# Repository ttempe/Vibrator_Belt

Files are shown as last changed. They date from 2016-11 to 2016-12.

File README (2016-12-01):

Vibrator Belt. 
Copyright 2016, Thomas TEMPE

The purpose of this project is to build a (physical) vibrating belt as
a tool for sensory augmentation.  The belt is fitted with coin
vibrators along its length. The one that points north vibrates at all
time.  Use it continuously for 6 weeks, and you will grow a sense of
direction. Take it off, and you will experience amputation.

For more background (and an award-winning product that you can
actually buy), see http://www.feelspace.de/navibelt/

Directory contents:
Leather belt/		DXF files for manufacturing the flexible part 
			of the belt (fabric, foam, steel band...)
			Can be edited with LibreCAD.
Belt buckle/		Fusion360 model of the buckle (for aluminium 
     			machining or 3D printing)
Vibrator_Leather_Belt/	Kicad files for making the flexible electronic 
			circuit (along the length of the belt)
Vibrator_Leather_Belt_Control_Box/  Kicd files for making the PCB 
			circuit that fits in the buckle.
Photos/			Photos of prototypes.
Code/			Arduino code for the microcontroller.
Arduino/		Arduino hardware support for the microcontroller.

The control board uses an ATMega32u4 at 8MHz.
To get it running:
* Install the Arduino IDE from Arduino.cc. Run it once, then quit it.
* Copy Arduino/*/ into your Documents/Arduino directory
* solder an 8MHz external oscillator on the back of the control board
* Start the Arduino IDE. Select Tools->Board: -> Atmega32u4 on a breadboard (8MHz internal clock)
* Connect the ISP connector to an ISP programmer. Select the proper port in Tools->Port
* Click Tools->burn bootloader
* remove the external oscillator
* Tools->Board:->LilyPad Arduino USB
* File->Examples->01. Basics->Blink
* Click « Upload » on the icon bar. The « Signal » LED should blink with 0.5Hz frequency.
* open code/Compass_band5_leather/compass_band5_leather.ino in Arduino
* Click the « upload » icon on the icon bar. control code should be uploading.

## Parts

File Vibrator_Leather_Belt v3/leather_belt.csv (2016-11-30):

Reference | Value | Footprint | Datasheet
SR1 | 74HC164 | SMD_Packages:SOIC-14_N
C_IN1 | CONN_01X04 | ttempe_lib:Vibrator_Chain_Cnx_5
C_OUT1 | CONN_01X04 | ttempe_lib:Vibrator_Chain_Cnx_5
R1 | 2k2 | Resistors_SMD:R_0603_HandSoldering
Q1 | Q_NPN_BEC | TO_SOT_Packages_SMD:SOT-23
V1 | Vibrator | ttempe_lib:Vibrator3
S1 | Solenoid | ttempe_lib:Vibrator_antenna2
R8 | 2k2 | Resistors_SMD:R_0603_HandSoldering
Q2 | Q_NPN_BEC | TO_SOT_Packages_SMD:SOT-23
V2 | Vibrator | ttempe_lib:Vibrator3
S2 | Solenoid | ttempe_lib:Vibrator_antenna2
R11 | 2k2 | Resistors_SMD:R_0603_HandSoldering
Q3 | Q_NPN_BEC | TO_SOT_Packages_SMD:SOT-23
V3 | Vibrator | ttempe_lib:Vibrator3
S3 | Solenoid | ttempe_lib:Vibrator_antenna2
R12 | 2k2 | Resistors_SMD:R_0603_HandSoldering
Q4 | Q_NPN_BEC | TO_SOT_Packages_SMD:SOT-23
V4 | Vibrator | ttempe_lib:Vibrator3
S4 | Solenoid | ttempe_lib:Vibrator_antenna2
R13 | 2k2 | Resistors_SMD:R_0603_HandSoldering
Q5 | Q_NPN_BEC | TO_SOT_Packages_SMD:SOT-23
V5 | Vibrator | ttempe_lib:Vibrator3
S5 | Solenoid | ttempe_lib:Vibrator_antenna2
R14 | 2k2 | Resistors_SMD:R_0603_HandSoldering
Q6 | Q_NPN_BEC | TO_SOT_Packages_SMD:SOT-23
V6 | Vibrator | ttempe_lib:Vibrator3
S6 | Solenoid | ttempe_lib:Vibrator_antenna2
R15 | 2k2 | Resistors_SMD:R_0603_HandSoldering
Q7 | Q_NPN_BEC | TO_SOT_Packages_SMD:SOT-23
V7 | Vibrator | ttempe_lib:Vibrator3
S7 | Solenoid | ttempe_lib:Vibrator_antenna2
R16 | 2k2 | Resistors_SMD:R_0603_HandSoldering
Q8 | Q_NPN_BEC | TO_SOT_Packages_SMD:SOT-23
V8 | Vibrator | ttempe_lib:Vibrator3
S8 | Solenoid | ttempe_lib:Vibrator_antenna2
C1 | 0.1 uF | Capacitors_SMD:C_0603_HandSoldering
C_IN2 | CONN_01X04 | ttempe_lib:Risym_8P_FCP
P1 | CONN_01X01 | Measurement_Points:Measurement_Point_Round-SMD-Pad_Big
P2 | CONN_01X01 | Measurement_Points:Measurement_Point_Round-SMD-Pad_Big

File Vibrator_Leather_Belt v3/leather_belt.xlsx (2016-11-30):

Reference | Value | Footprint | Datasheet
C_IN1 | CONN_01X04 | ttempe_lib:Vibrator_Chain_Cnx_5 | 不要焊
C_IN2 | CONN_01X04 | ttempe_lib:Risym_8P_FCP | 不要焊
C_OUT1 | CONN_01X04 | ttempe_lib:Vibrator_Chain_Cnx_5 | 不要焊
C1 | 0.1 uF | Capacitors_SMD:C_0603_HandSoldering
P1 | CONN_01X01 | Measurement_Points:Measurement_Point_Round-SMD-Pad_Big | 不要焊
P2 | CONN_01X01 | Measurement_Points:Measurement_Point_Round-SMD-Pad_Big | 不要焊
Q1 | Q_NPN_BEC | TO_SOT_Packages_SMD:SOT-23
Q2 | Q_NPN_BEC | TO_SOT_Packages_SMD:SOT-23
Q3 | Q_NPN_BEC | TO_SOT_Packages_SMD:SOT-23
Q4 | Q_NPN_BEC | TO_SOT_Packages_SMD:SOT-23
Q5 | Q_NPN_BEC | TO_SOT_Packages_SMD:SOT-23
Q6 | Q_NPN_BEC | TO_SOT_Packages_SMD:SOT-23
Q7 | Q_NPN_BEC | TO_SOT_Packages_SMD:SOT-23
Q8 | Q_NPN_BEC | TO_SOT_Packages_SMD:SOT-23
R1 | 2k2 | Resistors_SMD:R_0603_HandSoldering
R11 | 2k2 | Resistors_SMD:R_0603_HandSoldering
R12 | 2k2 | Resistors_SMD:R_0603_HandSoldering
R13 | 2k2 | Resistors_SMD:R_0603_HandSoldering
R14 | 2k2 | Resistors_SMD:R_0603_HandSoldering
R15 | 2k2 | Resistors_SMD:R_0603_HandSoldering
R16 | 2k2 | Resistors_SMD:R_0603_HandSoldering
R8 | 2k2 | Resistors_SMD:R_0603_HandSoldering
S1 | Solenoid | ttempe_lib:Vibrator_antenna2 | 不要焊
S2 | Solenoid | ttempe_lib:Vibrator_antenna2 | 不要焊
S3 | Solenoid | ttempe_lib:Vibrator_antenna2 | 不要焊
S4 | Solenoid | ttempe_lib:Vibrator_antenna2 | 不要焊
S5 | Solenoid | ttempe_lib:Vibrator_antenna2 | 不要焊
S6 | Solenoid | ttempe_lib:Vibrator_antenna2 | 不要焊
S7 | Solenoid | ttempe_lib:Vibrator_antenna2 | 不要焊
S8 | Solenoid | ttempe_lib:Vibrator_antenna2 | 不要焊
SR1 | 74HC164 | SMD_Packages:SOIC-14_N
V1 | Vibrator | ttempe_lib:Vibrator3 | 不要焊
V2 | Vibrator | ttempe_lib:Vibrator3 | 不要焊
V3 | Vibrator | ttempe_lib:Vibrator3 | 不要焊
V4 | Vibrator | ttempe_lib:Vibrator3 | 不要焊
V5 | Vibrator | ttempe_lib:Vibrator3 | 不要焊
V6 | Vibrator | ttempe_lib:Vibrator3 | 不要焊
V7 | Vibrator | ttempe_lib:Vibrator3 | 不要焊
V8 | Vibrator | ttempe_lib:Vibrator3 | 不要焊

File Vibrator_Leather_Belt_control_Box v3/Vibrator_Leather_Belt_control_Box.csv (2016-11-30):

Reference | Value | Footprint | Datasheet
P1 | USB_OTG | ttempe_lib:Micro_USB_MK5P
IC1 | TP4057 | TO_SOT_Packages_SMD:SOT-23-6
R5 | 3k | Resistors_SMD:R_0603_HandSoldering
R1 | 10k | Resistors_SMD:R_0603_HandSoldering
D_CHRG1 | LED_R | ttempe_lib:LED_1206_reversed
C1 | 10uF | Resistors_SMD:R_0805_HandSoldering
BAT1 | CONN_01X02 | ttempe_lib:Conn_1x2_2mm
D1 | 1N4448W | Diodes_SMD:SOD-123
SW1 | SWITCH_INV | ttempe_lib:SMD_side_switch_MSK-12C01-07
C5 | 10uF | Resistors_SMD:R_0805_HandSoldering
R6 | 2.2k | Resistors_SMD:R_0603_HandSoldering
R7 | 2.2k | Resistors_SMD:R_0603_HandSoldering
U2 | ATmega32U4-AU | Housings_QFP:TQFP-44_10x10mm_Pitch0.8mm
ISP1 | CONN_02X03 | Pin_Headers:Pin_Header_Straight_2x03
U1 | MIC5205 | TO_SOT_Packages_SMD:SOT-23-5
D_PW1 | LED_R | ttempe_lib:LED_1206_reversed
R8 | 1k | Resistors_SMD:R_0603_HandSoldering
C4 | .1uF | Resistors_SMD:R_0603_HandSoldering
R2 | 22 | Resistors_SMD:R_0603_HandSoldering
R3 | 22 | Resistors_SMD:R_0603_HandSoldering
C6 | 1uF | Resistors_SMD:R_0603_HandSoldering
C2 | .1uF | Resistors_SMD:R_0603_HandSoldering
D_DATA1 | Led_G | ttempe_lib:LED_1206_reversed
R4 | 1k | Resistors_SMD:R_0603_HandSoldering
R9 | 1k | Resistors_SMD:R_0603_HandSoldering
D_SIG1 | LED_G | ttempe_lib:LED_1206_reversed
R10 | 1.5 | Resistors_SMD:R_0603_HandSoldering
Q1 | Q_NPN_BEC | TO_SOT_Packages_SMD:SOT-23_Handsoldering
R11 | 2.2k | Resistors_SMD:R_0603_HandSoldering
IC2 | LSM303D | ttempe_lib:TFLGA-3.0x3.0x1.0_16L
C8 | 0.22uF | Resistors_SMD:R_0603_HandSoldering
C9 | 4.7uF | Resistors_SMD:R_0603_HandSoldering
C7 | .1uF | Resistors_SMD:R_0603_HandSoldering
C3 | .1uF | Resistors_SMD:R_0603_HandSoldering
SW2 | SW_PUSH | ttempe_lib:SMD_side_push_button_2x4x3.5
P2 | CONN_01X07 | ttempe_lib:Risym_8P_SMD
Y1 | Crystal_Small | Crystals:Crystal_HC49-SD_SMD
P3 | CONN_01X01 | Measurement_Points:Measurement_Point_Round-SMD-Pad_Small
P4 | CONN_01X01 | Measurement_Points:Measurement_Point_Round-SMD-Pad_Small

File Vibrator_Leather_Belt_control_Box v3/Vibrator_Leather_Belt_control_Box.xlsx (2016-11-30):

Reference | Value | Footprint | Supplied by | Besoin d'acheter
P1 | USB_OTG | ttempe_lib:Micro_USB_MK5P | Thomas
IC1 | TP4057 | TO_SOT_Packages_SMD:SOT-23-6 | Thomas
R5 | 3k | Resistors_SMD:R_0603_HandSoldering | Derry
R1 | 10k | Resistors_SMD:R_0603_HandSoldering | Derry
D_CHRG1 | LED_R | ttempe_lib:LED_1206_reversed | Thomas
C1 | 10uF | Resistors_SMD:R_0805_HandSoldering | Derry
BAT1 | CONN_01X02 | ttempe_lib:Conn_1x2_2mm | 不要焊
D1 | 1N4448W | Diodes_SMD:SOD-123 | Thomas
SW1 | SWITCH_INV | ttempe_lib:SMD_side_switch_MSK-12C01-07 | Thomas
C5 | 10uF | Resistors_SMD:R_0805_HandSoldering | Derry
R6 | 2.2k | Resistors_SMD:R_0603_HandSoldering | Derry
R7 | 2.2k | Resistors_SMD:R_0603_HandSoldering | Derry
U2 | ATmega32U4-AU | Housings_QFP:TQFP-44_10x10mm_Pitch0.8mm | Derry
ISP1 | CONN_02X03 | Pin_Headers:Pin_Header_Straight_2x03 | 不要焊
U1 | MIC5205 | TO_SOT_Packages_SMD:SOT-23-5 | Thomas
D_PW1 | LED_R | ttempe_lib:LED_1206_reversed | Thomas
R8 | 1k | Resistors_SMD:R_0603_HandSoldering | Derry
C4 | .1uF | Resistors_SMD:R_0603_HandSoldering | Derry
R2 | 22 | Resistors_SMD:R_0603_HandSoldering | Derry
R3 | 22 | Resistors_SMD:R_0603_HandSoldering | Derry
C6 | 1uF | Resistors_SMD:R_0603_HandSoldering | Derry
C2 | .1uF | Resistors_SMD:R_0603_HandSoldering | Derry
D_DATA1 | Led_G | ttempe_lib:LED_1206_reversed | Thomas
R4 | 1k | Resistors_SMD:R_0603_HandSoldering | Derry
R9 | 1k | Resistors_SMD:R_0603_HandSoldering | Derry
D_SIG1 | LED_G | ttempe_lib:LED_1206_reversed | Thomas
R10 | 1.5 | Resistors_SMD:R_0603_HandSoldering | Derry
Q1 | Q_NPN_BEC | TO_SOT_Packages_SMD:SOT-23_Handsoldering | Thomas
R11 | 2.2k | Resistors_SMD:R_0603_HandSoldering | Derry
IC2 | LSM303D | ttempe_lib:TFLGA-3.0x3.0x1.0_16L | Thomas
C8 | 0.22uF | Resistors_SMD:R_0603_HandSoldering | Derry
C9 | 4.7uF | Resistors_SMD:R_0603_HandSoldering | Derry
C7 | .1uF | Resistors_SMD:R_0603_HandSoldering | Derry
C3 | .1uF | Resistors_SMD:R_0603_HandSoldering | Derry
SW2 | SW_PUSH | ttempe_lib:SMD_side_push_button_2x4x3.5 | Thomas
P2 | CONN_01X07 | ttempe_lib:Risym_8P_SMD | Thomas
Y1 | Crystal_Small | Crystals:Crystal_HC49-SD_SMD | Thomas
P3 | CONN_01X01 | Measurement_Points:Measurement_Point_Round-SMD-Pad_Small | 不要焊
P4 | CONN_01X01 | Measurement_Points:Measurement_Point_Round-SMD-Pad_Small | 不要焊

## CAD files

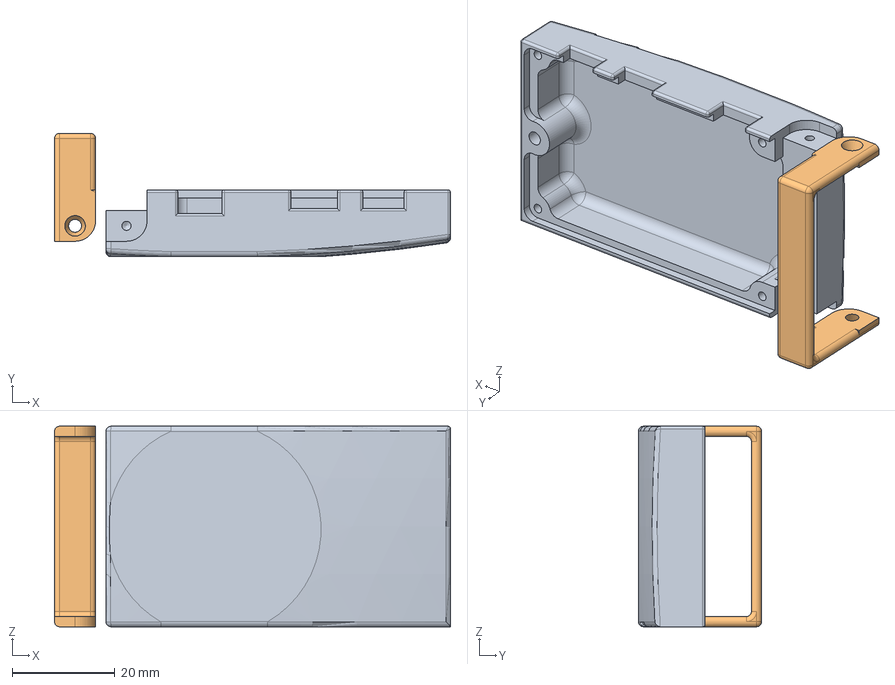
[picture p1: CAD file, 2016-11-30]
belt buckle 2/Vibrator belt buckle 2 v21 v10.step
77.0 x 24.0 x 39.0 mm

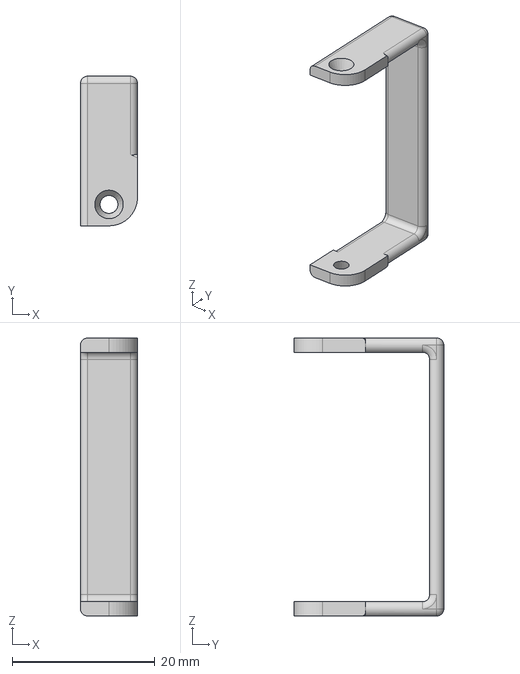
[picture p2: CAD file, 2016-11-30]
belt buckle 2/Clamp - elongated.stp
8.00 x 21.0 x 39.0 mm

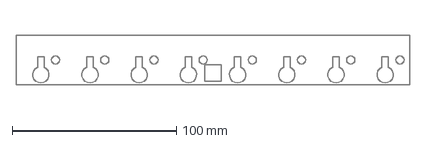
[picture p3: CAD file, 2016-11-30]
Leather Belt/foam v1.dxf
240.0 x 30.0 mm

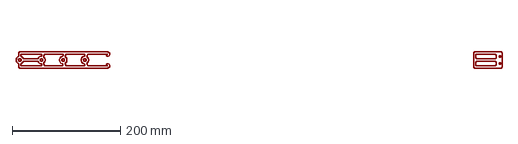
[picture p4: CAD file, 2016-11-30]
Leather Belt/belt v3.dxf
897.0 x 30.0 mm

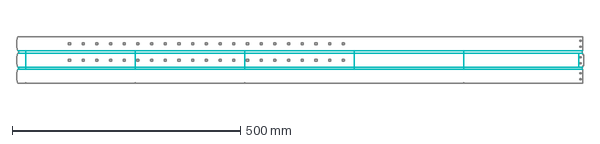
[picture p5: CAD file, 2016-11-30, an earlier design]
Leather Belt/belt v2.dxf
1244.0 x 101.0 mm

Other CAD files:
Leather Belt/belt v1.dxf

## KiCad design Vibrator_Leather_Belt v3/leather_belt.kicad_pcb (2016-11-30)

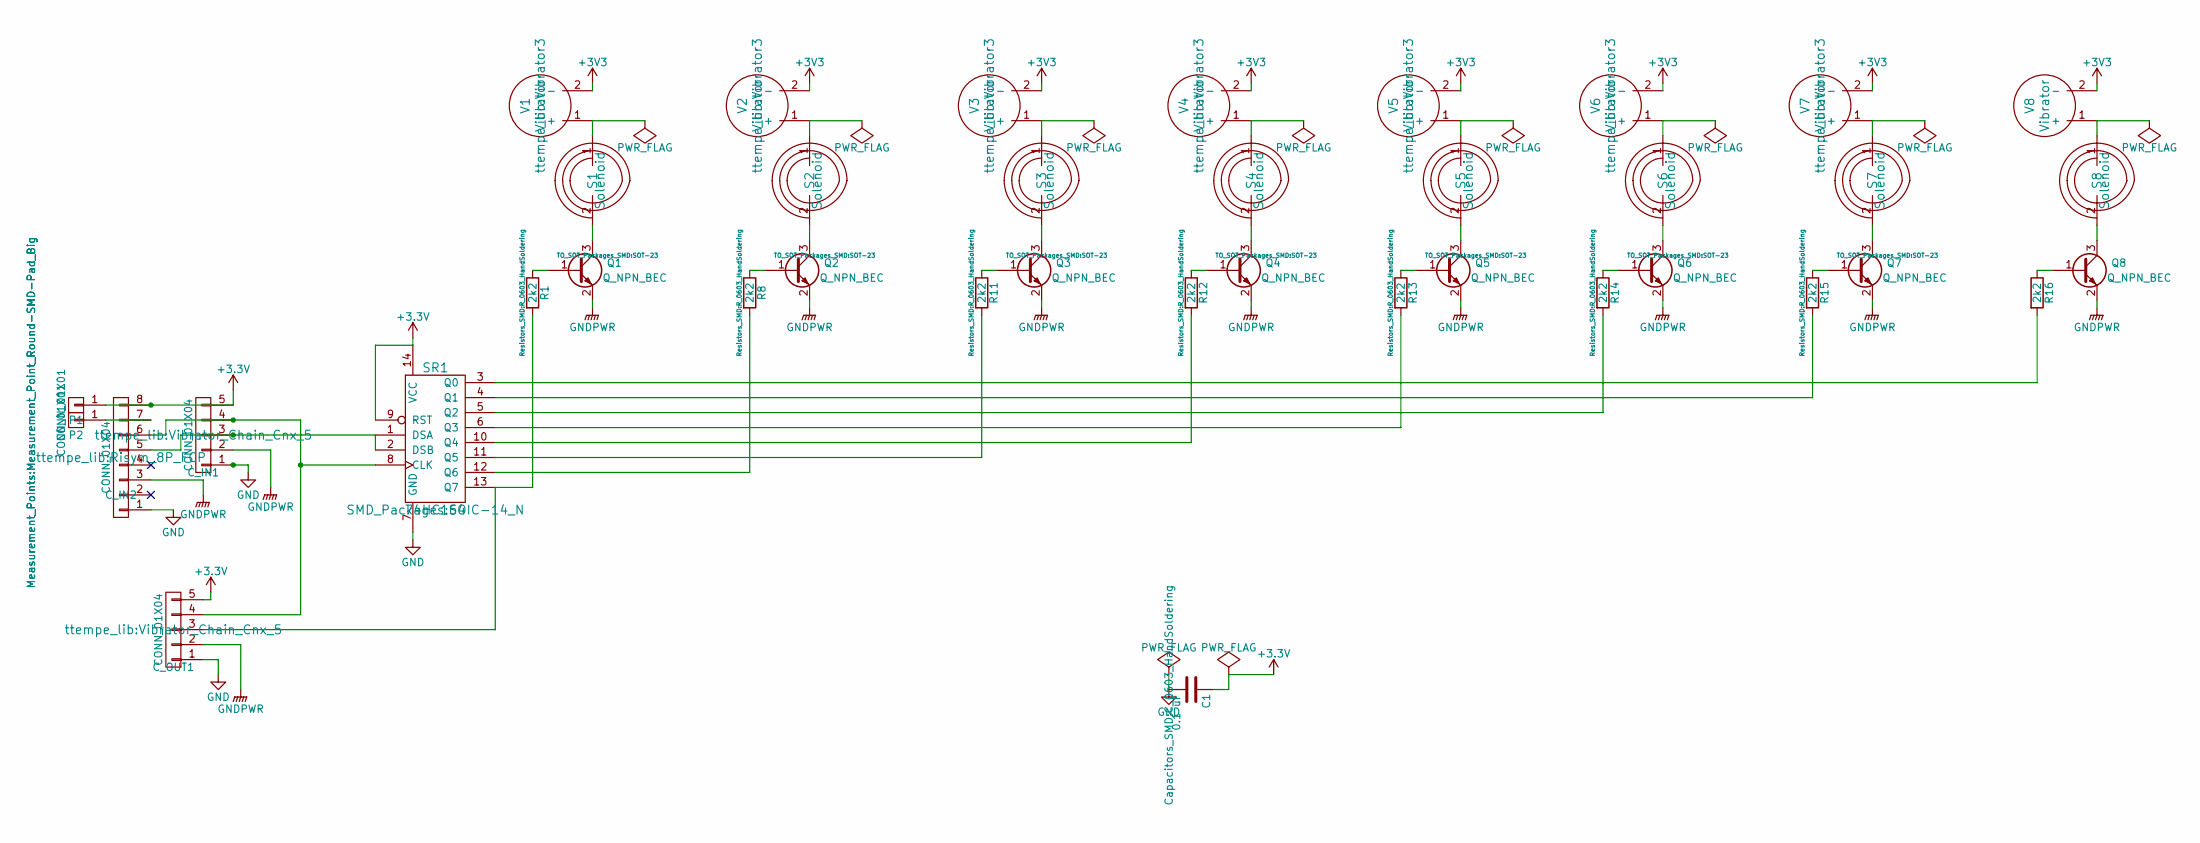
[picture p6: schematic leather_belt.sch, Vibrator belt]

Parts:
C1: 0.1 uF; C_0603_HandSoldering
C_IN1: CONN_01X04; Vibrator_Chain_Cnx_5
C_IN2: CONN_01X04; Risym_8P_FCP
C_OUT1: CONN_01X04; Vibrator_Chain_Cnx_5
P1, P2: CONN_01X01; Measurement_Point_Round-SMD-Pad_Big
Q1, Q2, Q3, Q4, Q5, Q6, Q7, Q8: Q_NPN_BEC; SOT-23
R1, R8, R11, R12, R13, R14, R15, R16: 2k2; R_0603_HandSoldering
S1, S2, S3, S4, S5, S6, S7, S8: Solenoid; Vibrator_antenna2
SR1: 74HC164; SOIC-14_N
V1, V2, V3, V4, V5, V6, V7, V8: Vibrator; Vibrator3

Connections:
GND: C1.2, C_IN1.1, C_IN2.1, C_OUT1.1, SR1.7 (GND)
GNDPWR: C_IN1.2, C_IN2.3, C_OUT1.2, Q1.2 (E), Q2.2 (E), Q3.2 (E), Q4.2 (E), Q5.2 (E), Q6.2 (E), Q7.2 (E), Q8.2 (E)
unnamed: C_IN1.3, C_IN2.5, SR1.1 (DSA), SR1.2 (DSB)
unnamed: C_IN1.4, C_IN2.6, C_OUT1.4, SR1.8 (CLK)
unnamed: C_IN2.7, P2.1
unnamed: C_OUT1.3, R1.2, SR1.13 (Q7)
unnamed: Q1.1 (B), R1.1
unnamed: Q1.3 (C), S1.2
unnamed: Q2.1 (B), R8.1
unnamed: Q2.3 (C), S2.2
unnamed: Q3.1 (B), R11.1
unnamed: Q3.3 (C), S3.2
unnamed: Q4.1 (B), R12.1
unnamed: Q4.3 (C), S4.2
unnamed: Q5.1 (B), R13.1
unnamed: Q5.3 (C), S5.2
unnamed: Q6.1 (B), R14.1
unnamed: Q6.3 (C), S6.2
unnamed: Q7.1 (B), R15.1
unnamed: Q7.3 (C), S7.2
unnamed: Q8.1 (B), R16.1
unnamed: Q8.3 (C), S8.2
unnamed: R8.2, SR1.12 (Q6)
unnamed: R11.2, SR1.11 (Q5)
unnamed: R12.2, SR1.10 (Q4)
unnamed: R13.2, SR1.6 (Q3)
unnamed: R14.2, SR1.5 (Q2)
unnamed: R15.2, SR1.4 (Q1)
unnamed: R16.2, SR1.3 (Q0)
unnamed: S1.1, V1.1 (+)
unnamed: S2.1, V2.1 (+)
unnamed: S3.1, V3.1 (+)
unnamed: S4.1, V4.1 (+)
unnamed: S5.1, V5.1 (+)
unnamed: S6.1, V6.1 (+)
unnamed: S7.1, V7.1 (+)
unnamed: S8.1, V8.1 (+)

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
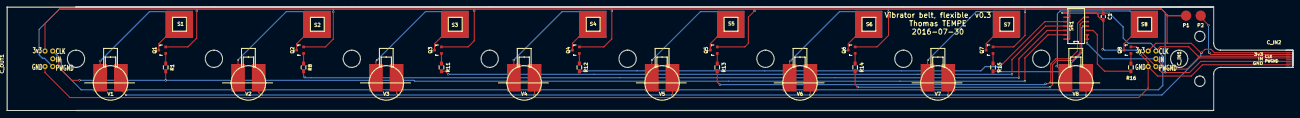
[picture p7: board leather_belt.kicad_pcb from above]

Board: 2 copper layers, 373.0 x 30.0 mm, 39 parts (0 on the bottom side), 38 nets.

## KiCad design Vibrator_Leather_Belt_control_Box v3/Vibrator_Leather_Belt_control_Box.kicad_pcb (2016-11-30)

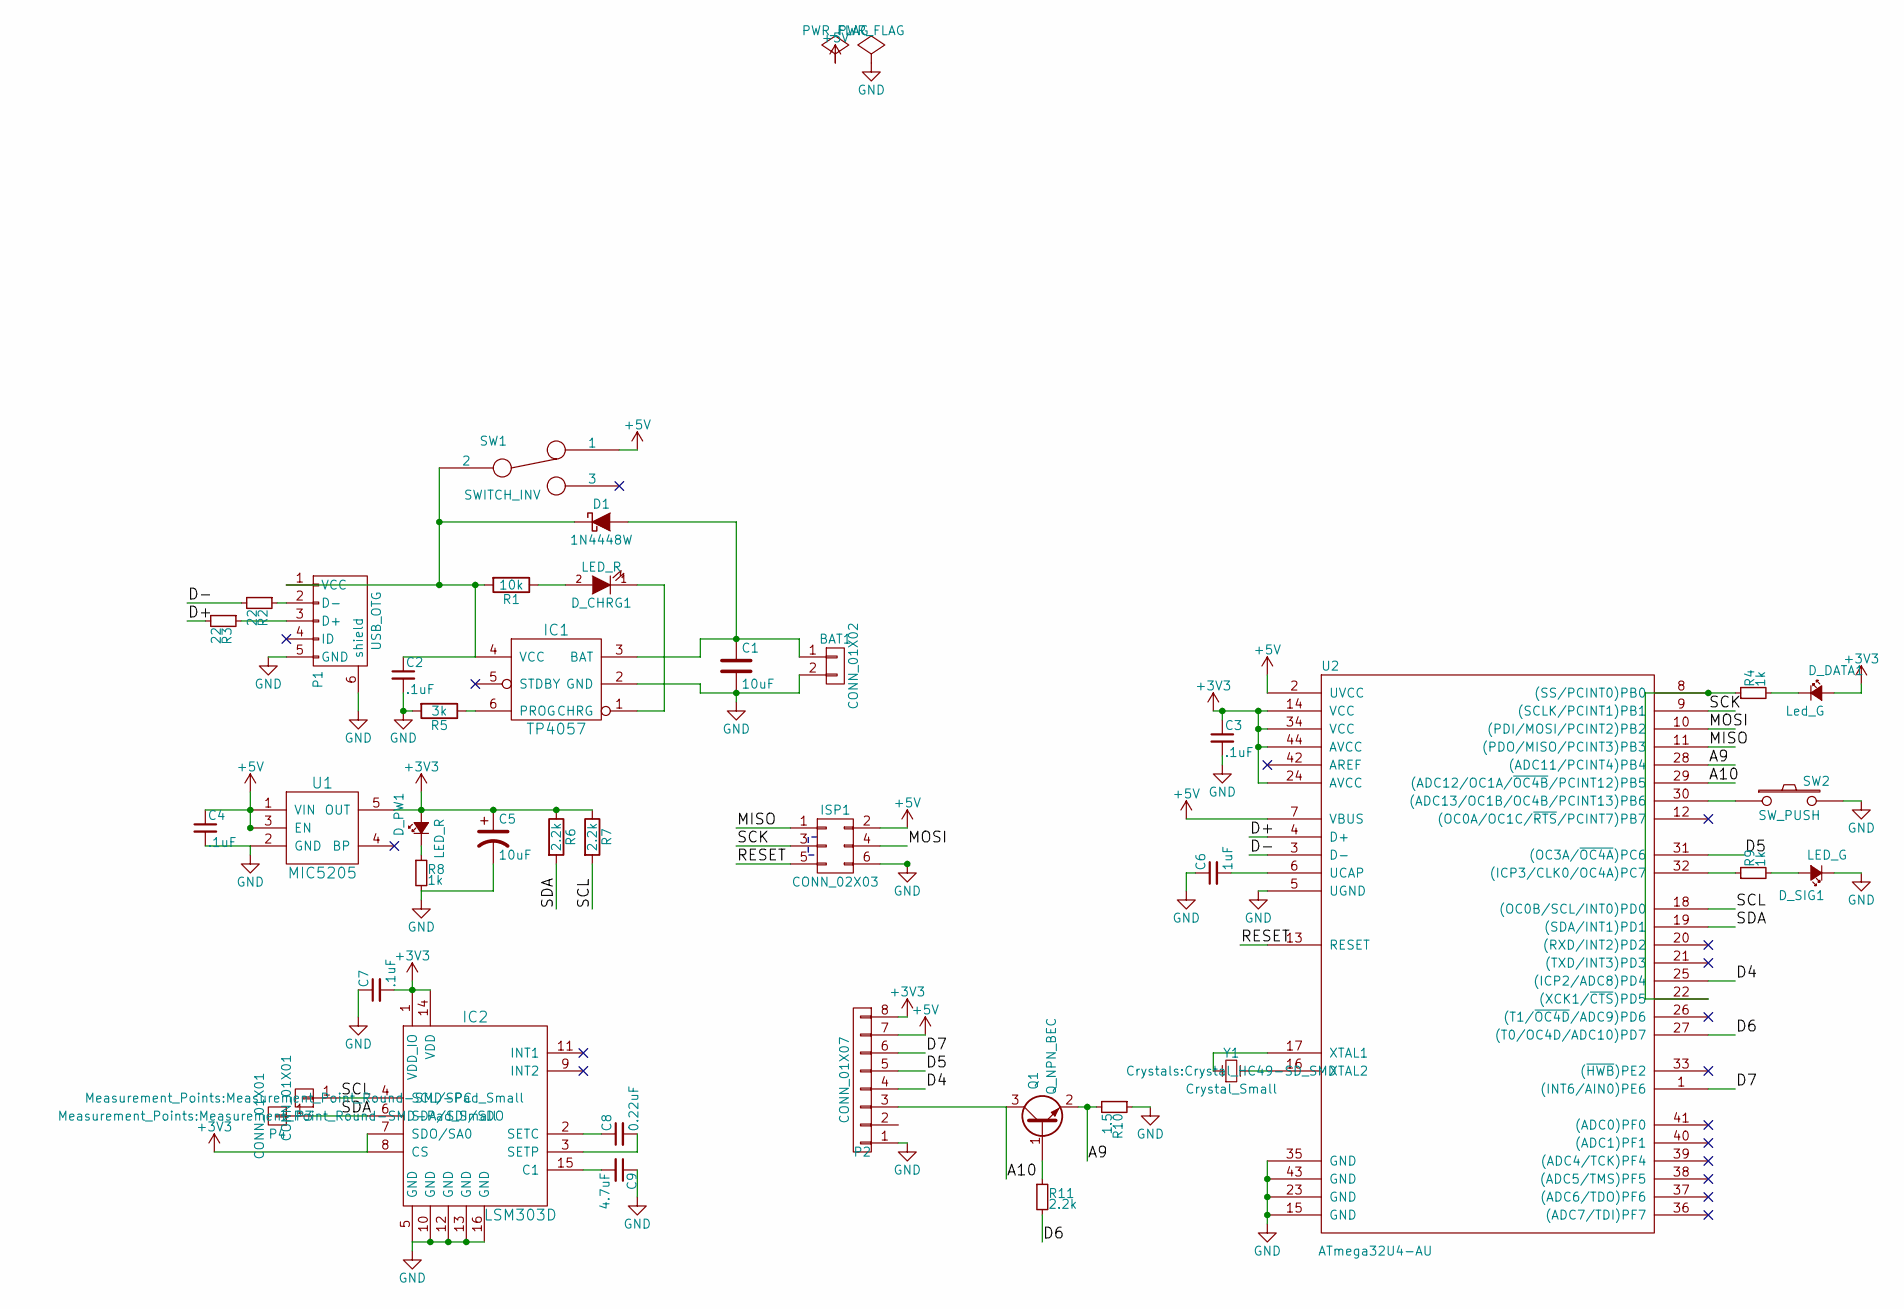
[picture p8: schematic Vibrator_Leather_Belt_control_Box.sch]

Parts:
BAT1: CONN_01X02; Conn_1x2_2mm
C1, C5: 10uF; R_0805_HandSoldering
C2, C3, C4, C7: .1uF; R_0603_HandSoldering
C6: 1uF; R_0603_HandSoldering
C8: 0.22uF; R_0603_HandSoldering
C9: 4.7uF; R_0603_HandSoldering
D1: 1N4448W; SOD-123
D_CHRG1: LED_R; LED_1206_reversed
D_DATA1: Led_G; LED_1206_reversed
D_PW1: LED_R; LED_1206_reversed
D_SIG1: LED_G; LED_1206_reversed
IC1: TP4057; SOT-23-6
IC2: LSM303D; TFLGA-3.0x3.0x1.0_16L
ISP1: CONN_02X03; Pin_Header_Straight_2x03
P1: USB_OTG; Micro_USB_MK5P
P2: CONN_01X07; Risym_8P_SMD
P3, P4: CONN_01X01; Measurement_Point_Round-SMD-Pad_Small
Q1: Q_NPN_BEC; SOT-23_Handsoldering
R1: 10k; R_0603_HandSoldering
R2, R3: 22; R_0603_HandSoldering
R4, R8, R9: 1k; R_0603_HandSoldering
R5: 3k; R_0603_HandSoldering
R6, R7, R11: 2.2k; R_0603_HandSoldering
R10: 1.5; R_0603_HandSoldering
SW1: SWITCH_INV; SMD_side_switch_MSK-12C01-07
SW2: SW_PUSH; SMD_side_push_button_2x4x3.5
U1: MIC5205; SOT-23-5
U2: ATmega32U4-AU; TQFP-44_10x10mm_Pitch0.8mm
Y1: Crystal_Small; Crystal_HC49-SD_SMD

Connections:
+3V3: C3.1, C5.1, C7.2, D_DATA1.2 (A), D_PW1.2 (A), IC2.1 (VDD_IO), IC2.7 (SDO/SA0), IC2.8 (CS), IC2.14 (VDD), P2.8, R6.1, R7.1, U1.5 (OUT), U2.14 (VCC), U2.24 (AVCC), U2.34 (VCC), U2.44 (AVCC)
+5V: C4.1, ISP1.2, P2.7, SW1.1, U1.1 (VIN), U1.3 (EN), U2.2 (UVCC), U2.7 (VBUS)
/A9: Q1.2 (E), R10.2, U2.28 ((ADC11/PCINT4)PB4)
/A10: P2.3, Q1.3 (C), U2.29 ((ADC12/OC1A/~OC4B~/PCINT12)PB5)
/D4: P2.4, U2.25 ((ICP2/ADC8)PD4)
/D5: P2.5, U2.31 ((OC3A/~OC4A~)PC6)
/D6: R11.2, U2.27 ((T0/OC4D/ADC10)PD7)
/D7: P2.6, U2.1 ((INT6/AIN0)PE6)
/D+: R3.2, U2.4 (D+)
/D-: R2.2, U2.3 (D-)
/MISO: ISP1.1, U2.11 ((PDO/MISO/PCINT3)PB3)
/MOSI: ISP1.4, U2.10 ((PDI/MOSI/PCINT2)PB2)
/RESET: ISP1.5, U2.13 (RESET)
/SCK: ISP1.3, U2.9 ((SCLK/PCINT1)PB1)
/SCL: IC2.4 (SCL/SPC), P3.1, R7.2, U2.18 ((OC0B/SCL/INT0)PD0)
/SDA: IC2.6 (SDA/SDI/SDO), P4.1, R6.2, U2.19 ((SDA/INT1)PD1)
GND: BAT1.2, C1.2, C2.2, C3.2, C4.2, C5.2, C6.1, C7.1, C9.1, D_SIG1.1 (K), IC1.2 (GND), IC2.5 (GND), IC2.10 (GND), IC2.12 (GND), IC2.13 (GND), IC2.16 (GND), ISP1.6, P1.5 (GND), P1.6 (shield), P2.1, R5.2, R8.2, R10.1, SW2.2, U1.2 (GND), U2.5 (UGND), U2.15 (GND), U2.23 (GND), U2.35 (GND), U2.43 (GND)
unnamed: BAT1.1, C1.1, D1.2 (A), IC1.3 (BAT)
unnamed: C2.1, D1.1 (K), IC1.4 (VCC), P1.1 (VCC), R1.2, SW1.2
unnamed: C6.2, U2.6 (UCAP)
unnamed: C8.1, IC2.2 (SETC)
unnamed: C8.2, IC2.3 (SETP)
unnamed: C9.2, IC2.15 (C1)
unnamed: D_CHRG1.1 (K), IC1.1 (CHRG)
unnamed: D_CHRG1.2 (A), R1.1
unnamed: D_DATA1.1 (K), R4.2
unnamed: D_PW1.1 (K), R8.1
unnamed: D_SIG1.2 (A), R9.2
unnamed: IC1.6 (PROG), R5.1
unnamed: P1.2 (D-), R2.1
unnamed: P1.3 (D+), R3.1
unnamed: Q1.1 (B), R11.1
unnamed: R4.1, U2.8 ((SS/PCINT0)PB0), U2.22 ((XCK1/~CTS~)PD5)
unnamed: R9.1, U2.32 ((ICP3/CLK0/OC4A)PC7)
unnamed: SW2.1, U2.30 ((ADC13/OC1B/OC4B/PCINT13)PB6)
unnamed: U2.16 (XTAL2), Y1.2
unnamed: U2.17 (XTAL1), Y1.1

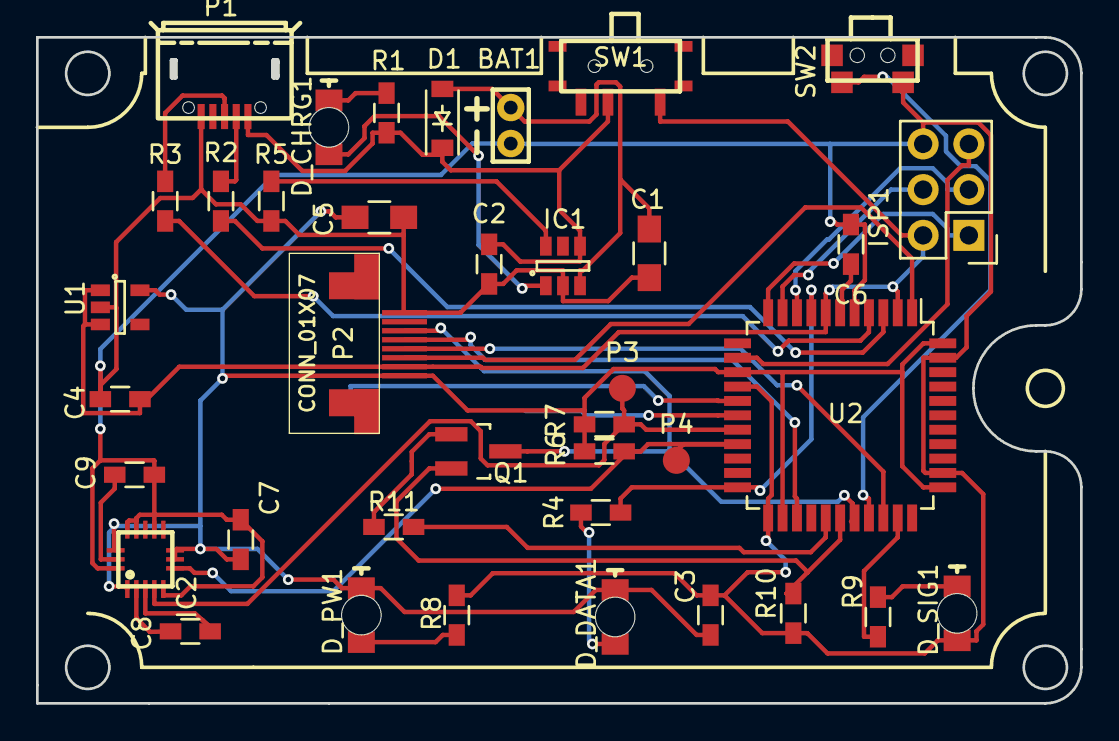
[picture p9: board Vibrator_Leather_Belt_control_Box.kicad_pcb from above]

Board: 2 copper layers, 58.0 x 37.0 mm, 39 parts (1 on the bottom side), 37 nets.

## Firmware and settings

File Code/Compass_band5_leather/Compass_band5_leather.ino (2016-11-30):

#include <Wire.h>
#include <LSM303.h>

#define data1Pin 7
#define clkPin 5
#define ledPin 13
#define maxNbVibrators 16
const char off = maxNbVibrators + 1;
const char nbUsefulVibrators = 14;
char currentVibrator = maxNbVibrators + 1;

/////////////////////////////////////////////////////////////////////////////////
LSM303 compass;

void setup() {
  pinMode(clkPin, OUTPUT);
  pinMode(data1Pin, OUTPUT);
  flick(maxNbVibrators, 0);

  Serial.begin(38400);  Wire.begin();
  compass.init();
  compass.enableDefault();
  compass.m_min = (LSM303::vector<int16_t>){-2569, -2656, -2405};  compass.m_max = (LSM303::vector<int16_t>){+2348, +2482, +2538}; // board + aluminium buckle
  compass.writeReg(0x20, 0x67); //CTRL1: accelerometer set to 100 Hz
  compass.writeReg(0x24, 0x74); //CTRL5: magnetometer set to 100 Hz
}

/////////////////////////////////////////////////////////////////////////////////
char outputMap1(char i){
  return i/8*8+(8-i%8);
}

char outputMap(char i){
  i *= 2;
  return i/8*8+(8-i%8);
}

void flick(char count, char turnOn){
  if (turnOn){
    digitalWrite(data1Pin, HIGH);
    delay(.001);
    digitalWrite(clkPin, HIGH);
    delay(.001);
    digitalWrite(clkPin, LOW);
    delay(.001);
    digitalWrite(data1Pin, LOW);
    delay(.001);
    count--;
    currentVibrator=1;
  }
  while(count-- > 0){
    digitalWrite(clkPin, HIGH);
    delay(.001);
    digitalWrite(clkPin, LOW); 
    delay(.001);
    currentVibrator++;
  }
}

void lightOne(char target){
  if (target == currentVibrator){
    //Do nothing 
  } else if (target>currentVibrator){
    flick(target-currentVibrator, 0);
  } else if (target+currentVibrator > maxNbVibrators) {
    flick(target, 1);
  } else {
    flick(maxNbVibrators-target, 0);
    flick(target, 1);
  }
}
/////////////////////////////////////////////////////////////////////////////////
void printHeading(float heading){
    for (int i = int(heading*78/360); i>0; i--) {
    Serial.print(" ");
  }
  Serial.println("*");
}


/////////////////////////////////////////////////////////////////////////////////
/////////////////////////////////////////////////////////////////////////////////
/////////////////////////////////////////////////////////////////////////////////
//Loop
void loop(){ loopa();}
/////////////////////////////////////////////////////////////////////////////////
////////////////////////////////////////////////////////////////////////////////
/////////////////////////////////////////////////////////////////////////////////
//Normal loop
void loopn() {
  //Serial.print("Reading...");
  compass.read();
  //Serial.print("Done\n");
    
  float heading = compass.heading((LSM303::vector<int>){0, 0, 1});
//  char headingVibrator = char((1-heading/360)*nbUsefulVibrators);
  char headingVibrator = char((heading/360)*nbUsefulVibrators);
  if (millis()%1000 > 150){ //turn on 150 ms every second 
    lightOne(off);
  }else {
    lightOne(outputMap(headingVibrator));
  }
  //Serial.println(heading);
  Serial.print(int(headingVibrator));
  printHeading(heading);
  delay(100);
}


/////////////////////////////////////////////////////////////////////////////////
//Calibrate
void loopc() {  
  static LSM303::vector<int16_t> running_min = {32767, 32767, 32767}, running_max = {-32768, -32768, -32768};
  char report[80]; 
  static int i=0;
  compass.read();
  running_min.x = min(running_min.x, compass.m.x);
  running_min.y = min(running_min.y, compass.m.y);
  running_min.z = min(running_min.z, compass.m.z);

  running_max.x = max(running_max.x, compass.m.x);
  running_max.y = max(running_max.y, compass.m.y);
  running_max.z = max(running_max.z, compass.m.z);
  
  snprintf(report, sizeof(report), "min: {%+6d, %+6d, %+6d}    max: {%+6d, %+6d, %+6d}",
    running_min.x, running_min.y, running_min.z,
    running_max.x, running_max.y, running_max.z);
  snprintf(report, sizeof(report), "%d, %d, %d", compass.m.x, compass.m.y, compass.m.z);
  Serial.println(report);
//  Serial.print(i++);  
  delay(100);
}

/////////////////////////////////////////////////////////////////////////////////
//Loop through all vibrators 

void loopa(){
  for (int i=0; i<nbUsefulVibrators; i++){
    lightOne(outputMap(i));
    digitalWrite(ledPin, i%2);
    delay(200);
  }
}


/////////////////////////////////////////////////////////////////////////////////
//Debugging

//Todo: try to correlate the values found below with physical vibrators. It's strange that we should get such high perturbation with so many vibrators, including possibly some which are not wired.

void loopd12(){
  lightOne(off);
  flick(0, 1);
  delay(1000);
}

//read the magnetic field X axis while flicking the vibrators
//Conclusion:
//There is a clear response, but it's actually coming from multiple vibrators: 1, 2, 3, 10, 11, 12, 25,33, 34, 35, 36, 41.
void loopd11(){ 
  int x=0;
  flick(0, 1);
  for (int v=0; v<off; v++){
    compass.read();
    Serial.print(compass.m.x);
    Serial.print(", ");
    flick(1,0);
    delay(20);
  }  
  Serial.print("\n");
}

//read the accelerometer at high frequency, and determine how hard it's vibrating
//Conclusion:
//Good discrimination when holding lightly in hand (immobile)
//Noise from start of belt when just laying
//When wearing and standing, Too much interference from movement to be useful.
void loopd10(){
  int x=0, i, v,val[20], sum=0, avg, std;
  compass.writeReg(0x20, 0x97); //CTRL1: accelerometer set to 800 Hz
  compass.writeReg(0x24, 0x00); //CTRL5: no magnetometer
  flick(0,1);

  for (v=0; v<off; v++){
    flick(1,0);
    delay(100);
    sum = 0;std=0;
    for (i=0; i<20; i++){
      compass.readAcc();
      val[i]=compass.a.x;
      sum += compass.a.x;
    }
    //calculate average
    avg = sum/20;
    for (i=0; i<20; i++){
      std+=abs(val[i]-avg)/4;
    }
    Serial.print(std);
    Serial.print(", ");
  }  
  Serial.print("\n");
}


//Reset the belt, measure magnetic field X, then activate vibrator V, and re-measure.
//Do this for each vibrator, in turn.
//If the belt is buckled, one should see a spike at corresponding vibrator.
//Conclusion:
//we can see something, but not so clearly...
void loopd9(){
  int x;
  for (int v=0; v<off; v++){
    delay(10);
    lightOne(off);
    compass.read();
    x = compass.m.x;
    lightOne(outputMap(v));
    delay(10);
    compass.read();
    Serial.print(compass.m.x-x);
    Serial.print(", ");
  }
  Serial.print("\n");
}

//read the magnetic field X axis while flicking the vibrators really fast.
//(X is where you see the strongest disturbance from the solenoids)
//Conclusion:
//Can't see clearly which vibrator is active
void loopd8(){
  int x=0;
  for (int v=0; v<off; v++){
    compass.read();
    Serial.print(compass.m.x-x);
    x = compass.m.x;
    Serial.print(", ");
    flick(1,0);
    delay(10);
  }  
  Serial.print("\n");
}

//read the magnetometer in a fast loop, and measure the time before it refreshes
//Conclusion: 
// * at default value: one update every 158 ms (long enough to read the magnetometer 75 times) 
// * at 100Hz nominal refresh: can get a new value every 10ms (long enough to read the magnetometer 4~5 times)
void loopd7(){
      int i, x;
      long int m;
      m = micros();
      x = compass.m.x;
      while (x ==  compass.m.x){
        x = compass.m.x;
        compass.read();
        i++;
      }
      Serial.print(micros()-m);    
      Serial.print(", ");    
      Serial.println(i);    


}


bool checkVibrator(char vibrator){
  //Make sure we're not reading the active vibrator
  if (vibrator==currentVibrator){ lightOne(off);}
  //Wait for the magnetometer to update
  int current = compass.m.x+compass.m.y+compass.m.z;
  while( compass.m.x+compass.m.y+compass.m.z == current){compass.read();};
  //Activate the vibrator we're checking
  delay(100);
  lightOne(vibrator);
  //Then wait until the new reading comes
  int x= compass.m.x;
  current = compass.m.x+compass.m.y+compass.m.z;
  while( compass.m.x+compass.m.y+compass.m.z == current){compass.read();};
  lightOne(off);
  Serial.print("Detected: ");Serial.println(compass.m.x-x);
  return (compass.m.x-x>100); 
}

void loopd6(){
  checkVibrator(outputMap(3));
  delay(500);
  lightOne(outputMap(3));
  delay(500);
}

void loopd5(){
    lightOne(outputMap(3));
    for (int i=0; i<1000; i++){
      compass.readMag();
      Serial.print(micros());Serial.print(" ");Serial.println(compass.m.z);
    }
}

void loopd4(){
  for (int i=0; i<maxNbVibrators; i++){
    compass.read();
    int mag = compass.m.x;
    lightOne(outputMap(i));
    delay(160);
    compass.read();
    int mag2 = compass.m.x;
    if (mag-mag2 > 100){
      Serial.print(mag-mag2); Serial.print(" ");
    }
    lightOne(off);
    delay(40);
  }
  Serial.print(".\n");
}

int intensity(){
  return sqrt(pow(compass.m.x-(compass.m_max.x-compass.m_min.x)/2, 2) + pow(compass.m.y-(compass.m_max.y-compass.m_min.y)/2,2) + pow(compass.m.z-(compass.m_max.z-compass.m_min.z)/2,2));
}

void loopd3(){
  lightOne(outputMap(1));
  for (int i=0; i<1000; i++){
    compass.read();Serial.println(intensity());
    Serial.print(compass.m.x-(compass.m_max.x-compass.m_min.x)/2);Serial.print(", ");
    Serial.print(compass.m.y-(compass.m_max.y-compass.m_min.y)/2);Serial.print(", ");
    Serial.print(compass.m.z-(compass.m_max.z-compass.m_min.z)/2);Serial.print("\n");
    delay(160);
  }
  Serial.println("");
  delay(0);
}


void loopd2(){
  compass.read();printHeading(compass.heading((LSM303::vector<int>){0, 0, 1}));
  lightOne(outputMap(14));
  for (int i=0; i<10; i++){
    compass.read();printHeading(compass.heading((LSM303::vector<int>){0, 0, 1}));
  }
  delay(1000);
  lightOne(outputMap(0));
  delay(1000);
  for (int i=0; i<10; i++){
    compass.read();printHeading(compass.heading((LSM303::vector<int>){0, 0, 1}));
  }
  delay(3000); 
}
